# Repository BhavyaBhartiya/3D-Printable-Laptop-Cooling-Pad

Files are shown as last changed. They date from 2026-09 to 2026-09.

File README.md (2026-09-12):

# 3D Printable Laptop Cooling Pad

This is an open source laptop cooling pad designed to force air into the laptop like the Ilano V10 Cooling Pad. It uses 2 Arctic P12 Pro fans set in back portion of the cooling pad instead of th emiddle as most laptops have ducts at the back and not in the middle. It also uses a custom RP2040 based board to control the fan speed on the basis of the temperature of the CPU if in automatic mode or to set the fans to a constant speed if in manual mode. It requires a seperate 12v Power Input to run it without increasing load on the laptop by using the laptop to supply power to it. If it is to be  used in automatic mode then it should be connected to the laptop by a seperate cable so that the laptop can provide it with the CPU temperatures.

## Instructons for Using and Assembly

1. Attach the PCB to the area enclosed by 3 thin walls in between the fan. The PCB should slip in and sit snugly in the enclosure as it has been built to the exact dimensions for the pcb.

2. If you plan on using only manual mode then connect the 6 pin usb c receptacle to an external 12V Power Supply. The 6 pin USB C receptacle is the one on the right of the RP2040 chip.

3. If you wish to use automatic mode as well then attach a cable from any port of the computer to the 14 pin usb c receptacle present straight ahead of the RP2040 chip.

4. The OLED scrren will show current mode, fan speed and if any fan is facing any errors. If it is in automatic mode then it will also show the CPU temperature which will be updated once every 5 seconds.

5. You can use the Increase/ Decrease Buttons to increase or decrease the RPM of the fan by 500 in Manual Mode.

6. You can use the Mode Button to toggle the Mode of the Cooling Pad.

## Schematic

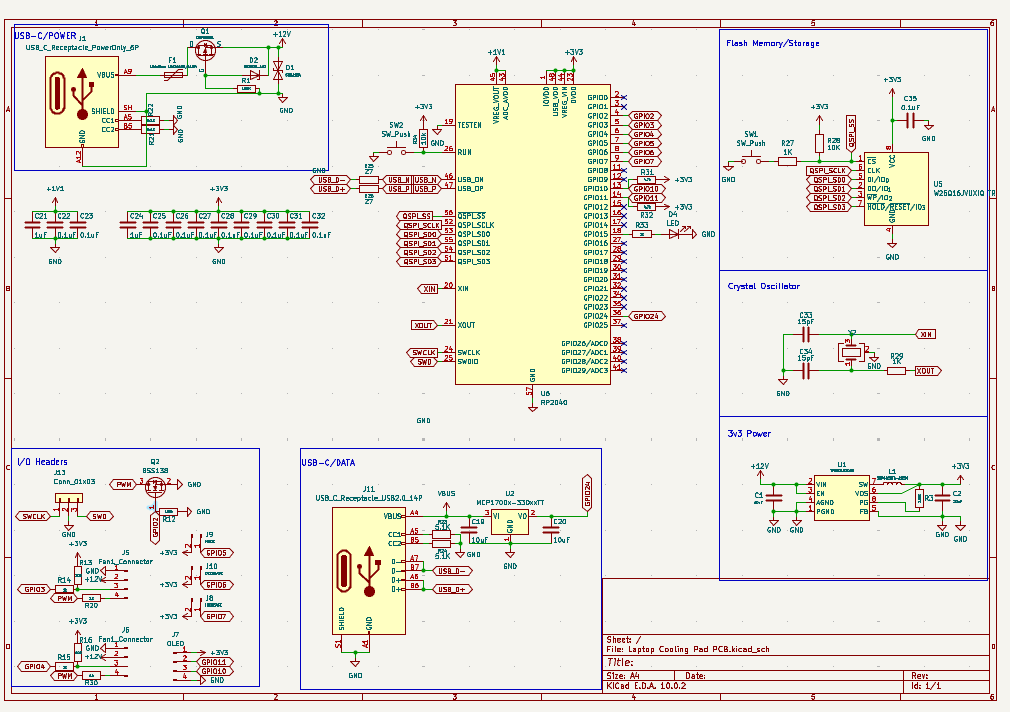
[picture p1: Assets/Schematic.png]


## PCB

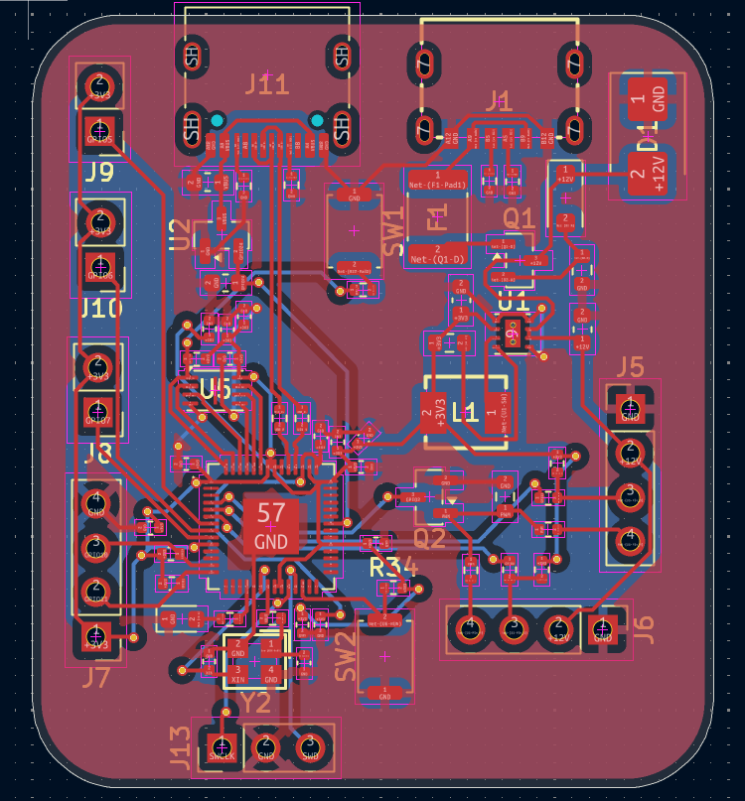
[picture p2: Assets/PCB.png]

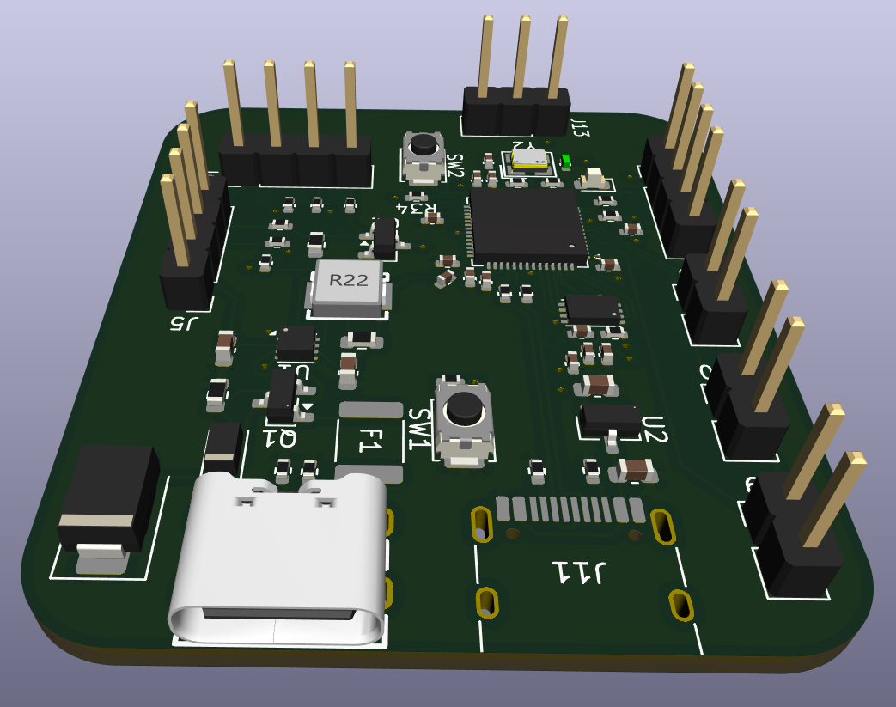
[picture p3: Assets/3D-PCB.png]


## 3D-Design

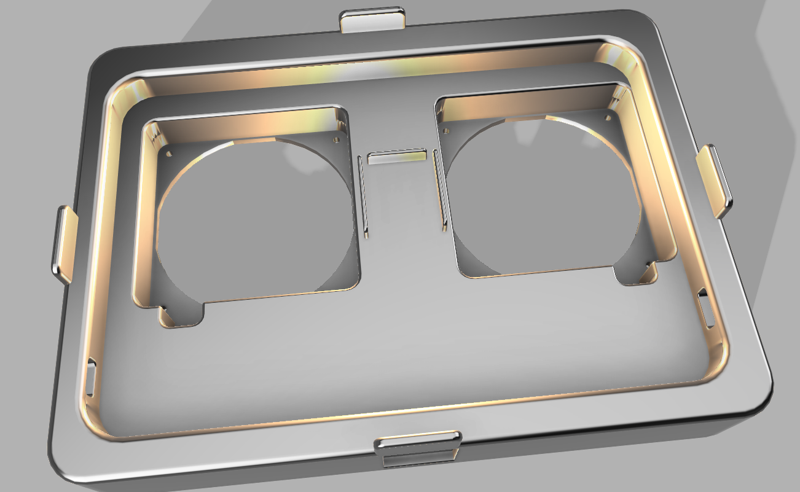
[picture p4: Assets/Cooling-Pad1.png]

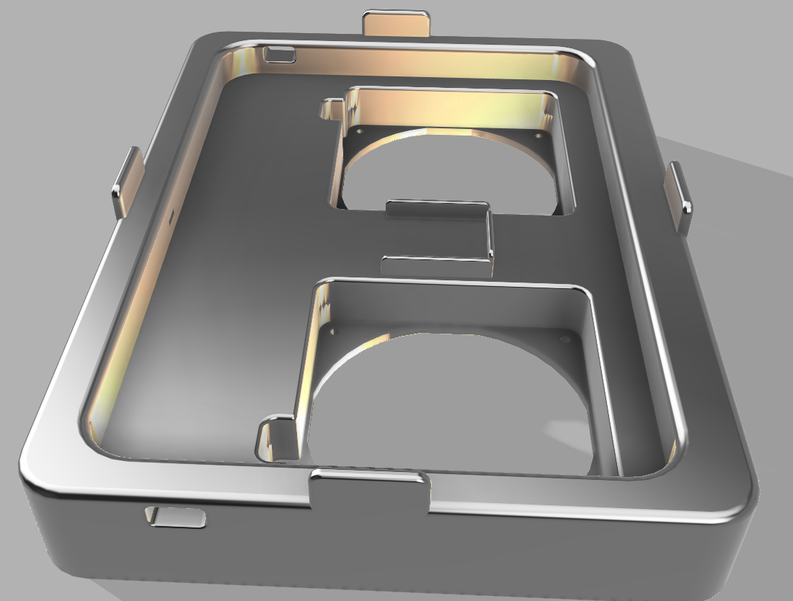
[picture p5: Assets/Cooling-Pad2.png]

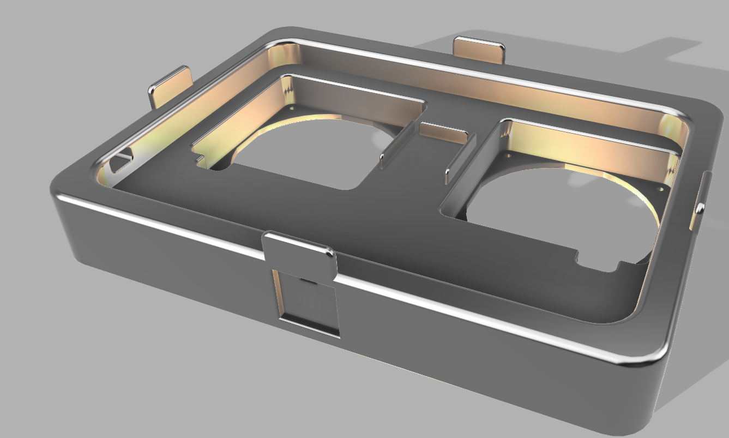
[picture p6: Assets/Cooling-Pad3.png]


## External Circuit

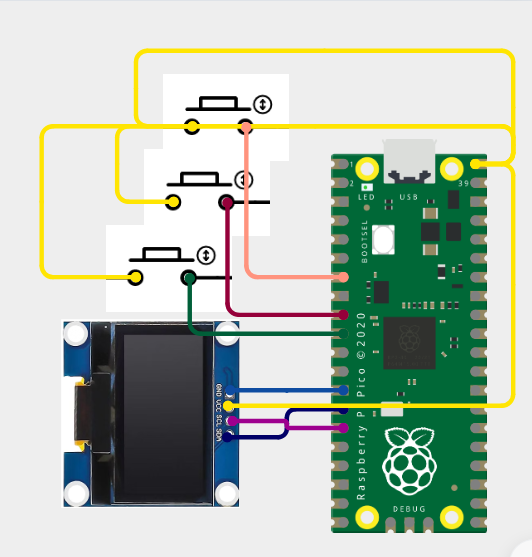
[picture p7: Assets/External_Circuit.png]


## BOM
| Designator | Footprint | Quantity | Value | LCSC Part # | Unit Price USD | Design Qty Cost USD | Link |
|---|---|---|---|---|---|---|---|
| C1, C19, C20 | 603 | 3 | 10uF | C96446 | 0.0557 | 0.1671 | https://www.lcsc.com/product-detail/C96446.html |
| C2 | 603 | 1 | 22uF | C2762594 | 0.1021 | 0.1021 | https://www.lcsc.com/product-detail/C2762594.html |
| C21, C24 | 402 | 2 | 1uF | C52923 | 0.0122 | 0.0244 | https://www.lcsc.com/product-detail/C52923.html |
| C22, C23, C25, C26, C27, C28, C29, C30, C31, C32, C35 | 402 | 11 | 0.1uF | C1525 | 0.0046 | 0.0506 | https://www.lcsc.com/product-detail/C1525.html |
| C33, C34 | 402 | 2 | 15pF | C86285 | 0.004 | 0.008 | https://www.lcsc.com/product-detail/C86285.html |
| D1 | D_SMB | 1 | SMBJ15A | C83846 | 0.1183 | 0.1183 | https://www.lcsc.com/product-detail/C83846.html |
| D2 | D_SOD-123F | 1 | BZT52H-A12 | C7507853 | 0.1912 | 0.1912 | https://www.lcsc.com/product-detail/C7507853.html |
| D4 | 603 | 1 | LED | C965804 | 0.0051 | 0.0051 | https://www.lcsc.com/product-detail/C965804.html |
| F1 | 1812 | 1 | Littelfuse 1812L150/24MR | C142805 | 0.0979 | 0.0979 | https://www.lcsc.com/product-detail/C142805.html |
| J1 | TYPE-C-SMD_TYPE-C-6P-073 | 1 | USB_C_Receptacle_PowerOnly_6P | C668623 | 0.0406 | 0.0406 | https://www.lcsc.com/product-detail/C668623.html |
| J10 | PinHeader_1x02_P2.54mm_Vertical | 1 | DECREASE | C32713268 | 0.0154 | 0.0154 | https://www.lcsc.com/product-detail/C32713268.html |
| J11 | USB_C_Receptacle_HRO_TYPE-C-31-M-12 | 1 | USB_C_Receptacle_USB2.0_14P | C165948 | 0.1724 | 0.1724 | https://www.lcsc.com/product-detail/C165948.html |
| J13 | PinHeader_1x03_P2.54mm_Vertical | 1 | Conn_01x03 | C2937625 | 0.0198 | 0.0198 | https://www.lcsc.com/product-detail/C2937625.html |
| J5, J6 | PinHeader_1x04_P2.54mm_Vertical | 2 | Fan1_Connector | C2691448 | 0.0275 | 0.055 | https://www.lcsc.com/product-detail/C2691448.html |
| J7 | PinHeader_1x04_P2.54mm_Vertical | 1 | OLED | C2691448 | 0.0275 | 0.0275 | https://www.lcsc.com/product-detail/C2691448.html |
| J8 | PinHeader_1x02_P2.54mm_Vertical | 1 | INCREASE | C32713268 | 0.0154 | 0.0154 | https://www.lcsc.com/product-detail/C32713268.html |
| J9 | PinHeader_1x02_P2.54mm_Vertical | 1 | MODE | C32713268 | 0.0154 | 0.0154 | https://www.lcsc.com/product-detail/C32713268.html |
| L1 | IND-SMD_L4.5-W4.1_SRP4020TA | 1 | SRP4020TA-2R2M | C719179 | 0.6015 | 0.6015 | https://www.lcsc.com/product-detail/C719179.html |
| Q1 | SOT-23 | 1 | DMP3099L | C2940610 | 0.0499 | 0.0499 | https://www.lcsc.com/product-detail/C2940610.html |
| Q2 | SOT-23 | 1 | BSS138 | C52895 | 0.0638 | 0.0638 | https://www.lcsc.com/product-detail/C52895.html |
| R1, R12, R3 | 603 | 3 | 100K | C14675 | 0.0036 | 0.0108 | https://www.lcsc.com/product-detail/C14675.html |
| R13, R16, R28, R34 | 402 | 4 | 10K | C60490 | 0.0033 | 0.0132 | https://www.lcsc.com/product-detail/C60490.html |
| R14, R15, R20, R27, R29, R30, R33 | 402 | 7 | 1k | C106235 | 0.0044 | 0.0308 | https://www.lcsc.com/product-detail/C106235.html |
| R21, R22, R23, R24 | 402 | 4 | 5.1K | C105872 | 0.003 | 0.012 | https://www.lcsc.com/product-detail/C105872.html |
| R25, R26 | 402 | 2 | 27 | C138021 | 0.004 | 0.008 | https://www.lcsc.com/product-detail/C138021.html |
| R31, R32 | 402 | 2 | 4.7k | C105871 | 0.0038 | 0.0076 | https://www.lcsc.com/product-detail/C105871.html |
| SW1, SW2 | SW_Push_SPST_NO_Alps_SKRK | 2 | SW_Push | C720477 | 0.053 | 0.106 | https://www.lcsc.com/product-detail/C720477.html |
| U1 | WSON-8-1EP_2x2mm_P0.5mm_EP0.9x1.6mm_ThermalVias | 1 | TPS62162DSG | C2863597 | 1.5159 | 1.5159 | https://www.lcsc.com/product-detail/C2863597.html |
| U2 | SOT-23 | 1 | MCP1700x-330xxTT | C39051 | 0.409 | 0.409 | https://www.lcsc.com/product-detail/C39051.html |
| U5 | Winbond_USON-8-1EP_3x2mm_P0.5mm_EP0.2x1.6mm | 1 | W25Q16JVUXIQ TR | C2843335 | 1.5882 | 1.5882 | https://www.lcsc.com/product-detail/C2843335.html |
| U6 | QFN-56-1EP_7x7mm_P0.4mm_EP3.2x3.2mm | 1 | RP2040 | C2040 | 0.9968 | 0.9968 | https://www.lcsc.com/product-detail/C2040.html |
| Y2 | CRYSTAL-SMD_4P-L2.5-W2.0-BL-1 | 1 | ABM8-272-T3 | C20625731 | 0.62 | 0.62 | https://lcsc.com/product-detail/Crystals_Abracon-LLC-ABM8-272-T3_C20625731.html |
| Arctic P12 Pro | | 2 | | | 16.23 | 32.46 | https://www.arctic.de/en/P12-Pro/ACFAN00305A |
| TOTAL | | 66 | | | | 39.6197 | |

### Credits - to KaiPereira for their excellent guide on [how to buid a custom devboard](https://github.com/KaiPereira/build-a-devboard)

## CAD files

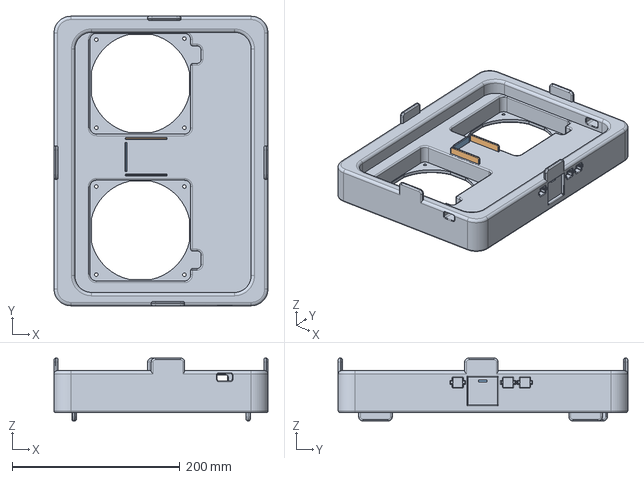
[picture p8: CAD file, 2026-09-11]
src/3D-Print/Laptop Cooling Pad.step
255.0 x 345.0 x 75.0 mm

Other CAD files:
src/3D-Print/Laptop Cooling Pad.f3d

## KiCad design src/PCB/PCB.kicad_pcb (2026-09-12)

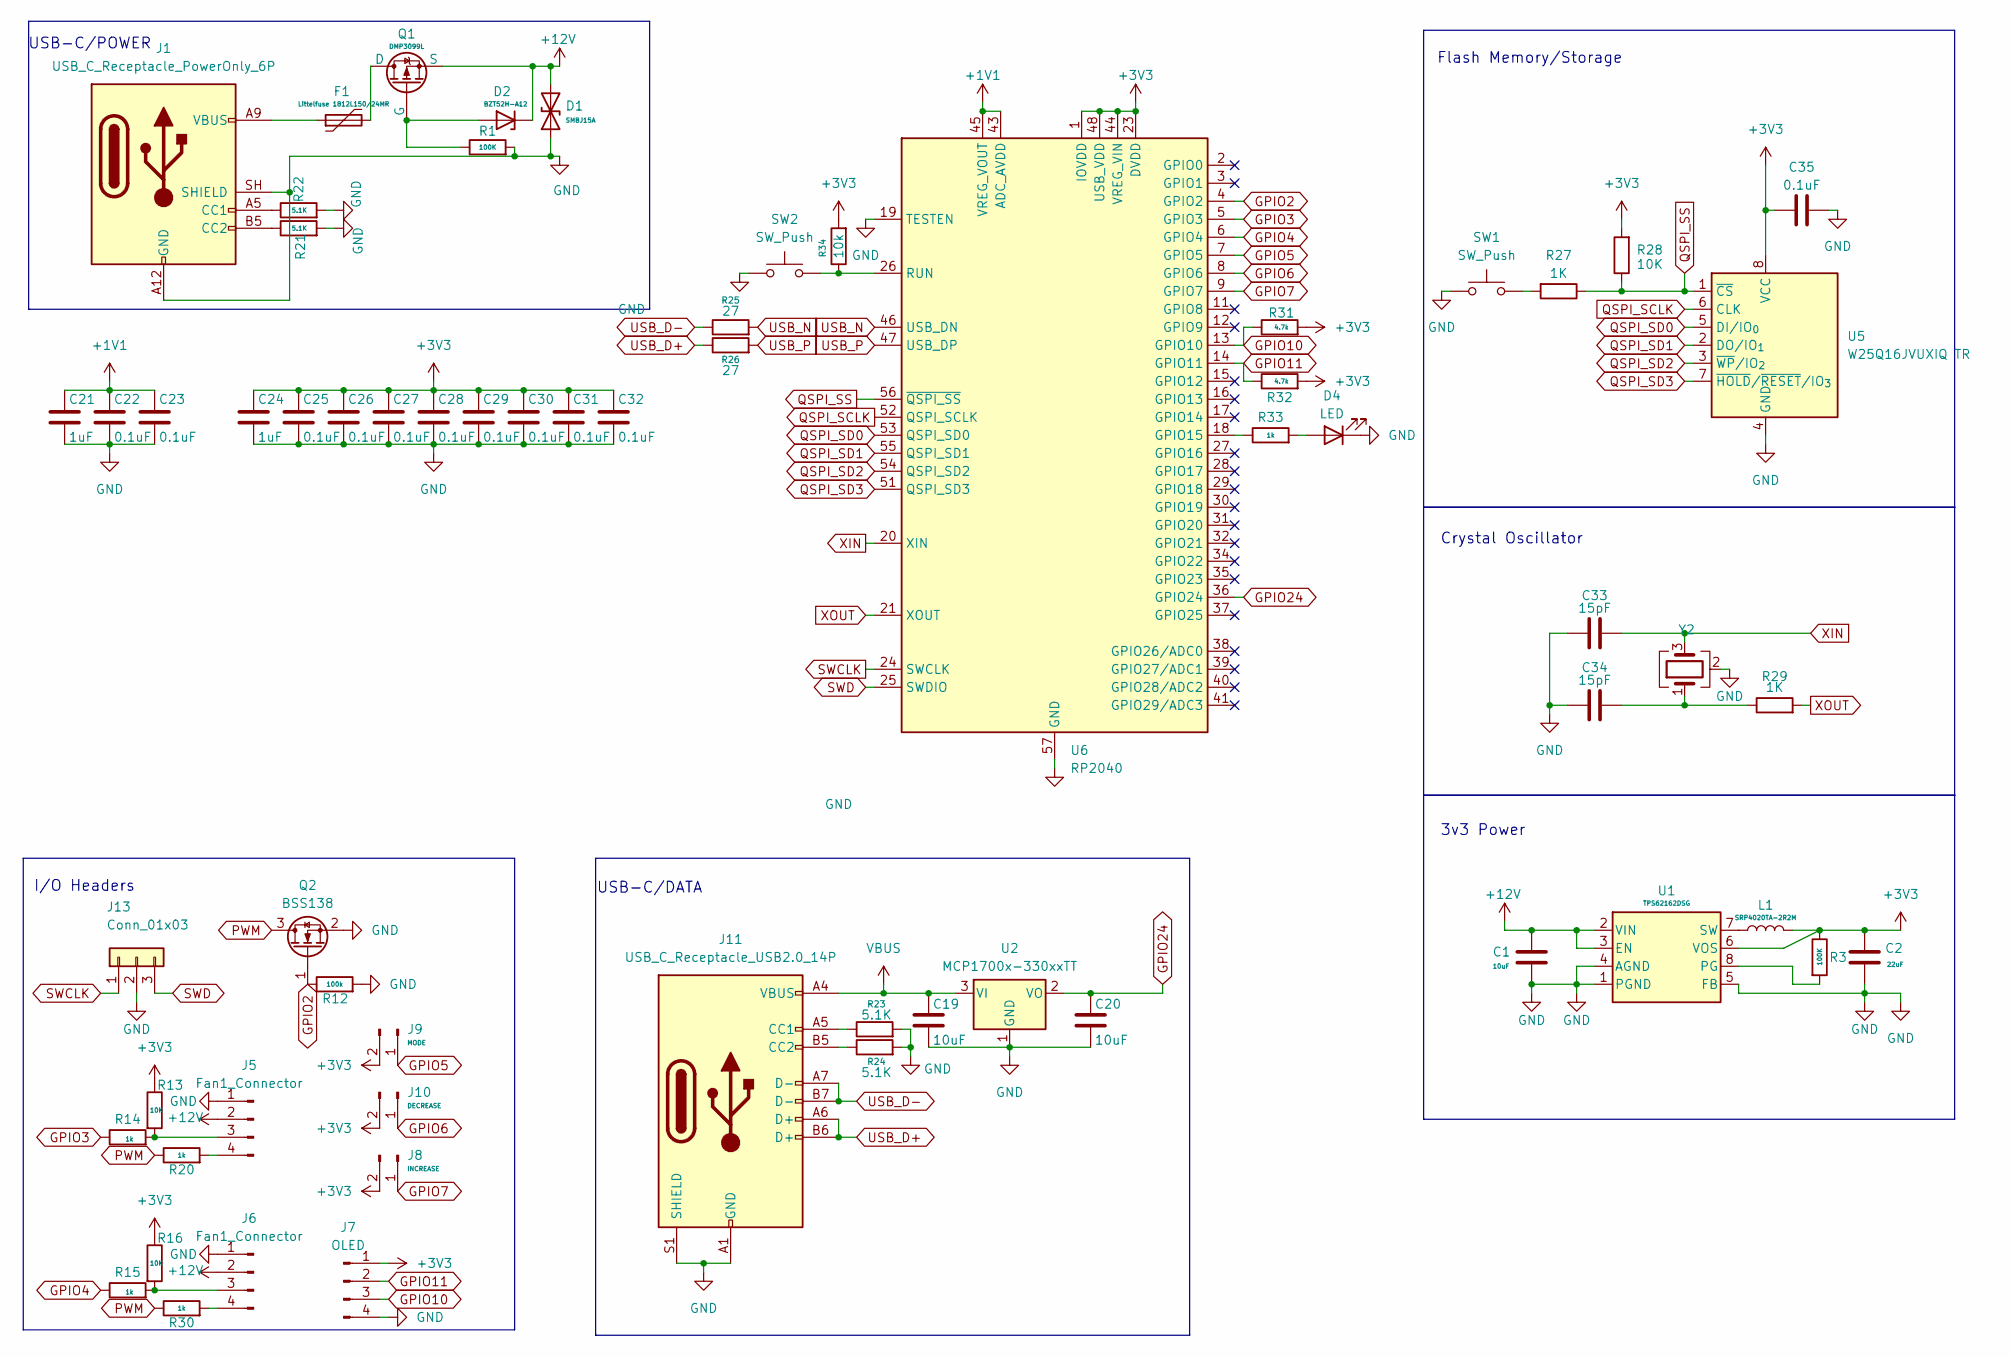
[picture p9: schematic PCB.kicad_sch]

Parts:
C1, C19, C20: 10uF; C_0603_1608Metric; LCSC Part Number C96446
C2: 22uF; C_0603_1608Metric; LCSC Part Number C2762594
C21, C24: 1uF; C_0402_1005Metric; LCSC Part Number C52923
C22, C23, C25, C26, C27, C28, C29, C30, C31, C32, C35: 0.1uF; C_0402_1005Metric; LCSC Part Number C1525
C33, C34: 15pF; C_0402_1005Metric; LCSC Part Number C86285
D1: SMBJ15A; D_SMB; LCSC Part Number C83846
D2: BZT52H-A12; D_SOD-123F; LCSC Part Number C7507853
D4: LED; LED_0603_1608Metric; LCSC Part Number C965804
F1: Littelfuse 1812L150/24MR; Fuse_1812_4532Metric; LCSC Part Number C142805
J1: USB_C_Receptacle_PowerOnly_6P; TYPE-C-SMD_TYPE-C-6P-073; LCSC Part Number TYPE-C 6P(073)
J5, J6: Fan1_Connector; PinHeader_1x04_P2.54mm_Vertical; LCSC Part Number C2691448
J7: OLED; PinHeader_1x04_P2.54mm_Vertical; LCSC Part Number C2691448
J8: INCREASE; PinHeader_1x02_P2.54mm_Vertical; LCSC Part Number C32713268
J9: MODE; PinHeader_1x02_P2.54mm_Vertical; LCSC Part Number C32713268
J10: DECREASE; PinHeader_1x02_P2.54mm_Vertical; LCSC Part Number C32713268
J11: USB_C_Receptacle_USB2.0_14P; USB_C_Receptacle_HRO_TYPE-C-31-M-12; LCSC Part Number C165948
J13: Conn_01x03; PinHeader_1x03_P2.54mm_Vertical; LCSC Part Number C2937625
L1: SRP4020TA-2R2M; IND-SMD_L4.5-W4.1_SRP4020TA; LCSC Part Number C719179
Q1: DMP3099L; SOT-23; LCSC Part Number C2940610
Q2: BSS138; SOT-23; LCSC Part Number C52895
R1, R3: 100K; R_0603_1608Metric; LCSC Part Number C14675
R12: 100k; R_0603_1608Metric; LCSC Part Number C14675
R13, R16, R28: 10K; R_0402_1005Metric; LCSC Part Number C60490
R14, R15, R20, R30, R33: 1k; R_0402_1005Metric; LCSC Part Number C106235
R21, R22, R23, R24: 5.1K; R_0402_1005Metric; LCSC Part Number C105872
R25, R26: 27; R_0402_1005Metric; LCSC Part Number C138021
R27, R29: 1K; R_0402_1005Metric; LCSC Part Number C106235
R31, R32: 4.7k; R_0402_1005Metric; LCSC Part Number C105871
R34: 10k; R_0402_1005Metric; LCSC Part Number C60490
SW1, SW2: SW_Push; SW_Push_SPST_NO_Alps_SKRK; LCSC Part Number C720477
U1: TPS62162DSG; WSON-8-1EP_2x2mm_P0.5mm_EP0.9x1.6mm_ThermalVias; LCSC Part Number C2863597
U2: MCP1700x-330xxTT; SOT-23; LCSC Part Number C39051
U5: W25Q16JVUXIQ TR; Winbond_USON-8-1EP_3x2mm_P0.5mm_EP0.2x1.6mm; LCSC Part Number C2843335
U6: RP2040; QFN-56-1EP_7x7mm_P0.4mm_EP3.2x3.2mm; LCSC Part Number C2040
Y2: ABM8-272-T3; CRYSTAL-SMD_4P-L2.5-W2.0-BL-1; LCSC Part Number C20625731

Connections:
+1V1: C21.1, C22.1, C23.1, U6.43 (ADC_AVDD), U6.45 (VREG_VOUT)
+3V3: C2.1, C24.1, C25.1, C26.1, C27.1, C28.1, C29.1, C30.1, C31.1, C32.1, C35.1, J7.1, J8.2, J9.2, J10.2, L1.2, R3.1, R13.1, R16.1, R28.2, R31.2, R32.2, R34.2, U1.6 (VOS), U5.8 (VCC), U6.1 (IOVDD), U6.10 (IOVDD), U6.22 (IOVDD), U6.23 (DVDD), U6.33 (IOVDD), U6.42 (IOVDD), U6.44 (VREG_VIN), U6.48 (USB_VDD), U6.49 (IOVDD), U6.50 (DVDD)
+12V: C1.1, D1.2 (A2), D2.1 (K), J5.2, J6.2, Q1.3 (S), U1.2 (VIN), U1.3 (EN)
GND: C1.2, C2.2, C19.2, C20.2, C21.2, C22.2, C23.2, C24.2, C25.2, C26.2, C27.2, C28.2, C29.2, C30.2, C31.2, C32.2, C33.1, C34.1, C35.2, D1.1 (A1), D4.1 (K), J1.A12 (GND), J1.B12 (GND), J1.SH (SHIELD), J5.1, J6.1, J7.4, J11.A1 (GND), J11.A12 (GND), J11.B1 (GND), J11.B12 (GND), J11.S1 (SHIELD), J13.2, Q2.2 (S), R1.2, R12.2, R21.2, R22.2, R23.2, R24.2, SW1.1, SW2.1, U1.1 (PGND), U1.4 (AGND), U1.5 (FB), U2.1 (GND), U5.4 (GND), U6.19 (TESTEN), U6.57 (GND), Y2.2 (G), Y2.4 (G)
GPIO2: Q2.1 (G), R12.1, U6.4 (GPIO2)
GPIO3: R14.1, U6.5 (GPIO3)
GPIO4: R15.1, U6.6 (GPIO4)
GPIO5: J9.1, U6.7 (GPIO5)
GPIO6: J10.1, U6.8 (GPIO6)
GPIO7: J8.1, U6.9 (GPIO7)
GPIO10: J7.3, R31.1, U6.13 (GPIO10)
GPIO11: J7.2, R32.1, U6.14 (GPIO11)
GPIO24: C20.1, U2.2 (VO), U6.36 (GPIO24)
unnamed: C34.2, R29.1, Y2.1
unnamed: D2.2 (A), Q1.2 (G), R1.1
unnamed: D4.2 (A), R33.2
unnamed: F1.1, J1.A9 (VBUS), J1.B9 (VBUS)
unnamed: J1.A5 (CC1), R21.1
unnamed: J1.B5 (CC2), R22.1
unnamed: J5.3, R13.2, R14.2
unnamed: J5.4, R20.2
unnamed: J6.3, R15.2, R16.2
unnamed: J6.4, R30.2
unnamed: J11.A5 (CC1), R23.1
unnamed: J11.B5 (CC2), R24.1
unnamed: F1.2, Q1.1 (D)
unnamed: R27.2, SW1.2
unnamed: R3.2, U1.8 (PG)
unnamed: L1.1, U1.7 (SW)
unnamed: R33.1, U6.18 (GPIO15)
unnamed: R34.1, SW2.2, U6.26 (RUN)
PWM: Q2.3 (D), R20.1, R30.1
QSPI_SCLK: U5.6 (CLK), U6.52 (QSPI_SCLK)
QSPI_SD0: U5.5 (DI/IO_{0}), U6.53 (QSPI_SD0)
QSPI_SD1: U5.2 (DO/IO_{1}), U6.55 (QSPI_SD1)
QSPI_SD2: U5.3 (~WP/IO_{2}), U6.54 (QSPI_SD2)
QSPI_SD3: U5.7 (~HOLD/~RESET/IO_{3}), U6.51 (QSPI_SD3)
QSPI_SS: R27.1, R28.1, U5.1 (~CS), U6.56 (~QSPI_SS)
SWCLK: J13.1, U6.24 (SWCLK)
SWD: J13.3, U6.25 (SWDIO)
USB_D+: J11.A6 (D+), J11.B6 (D+), R26.1
USB_D-: J11.A7 (D-), J11.B7 (D-), R25.1
USB_N: R25.2, U6.46 (USB_DN)
USB_P: R26.2, U6.47 (USB_DP)
VBUS: C19.1, J11.A4 (VBUS), J11.A9 (VBUS), J11.B4 (VBUS), J11.B9 (VBUS), U2.3 (VI)
XIN: C33.2, U6.20 (XIN), Y2.3
XOUT: R29.2, U6.21 (XOUT)

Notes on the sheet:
I/O Headers
USB-C/DATA
Crystal Oscillator
Flash Memory/Storage
USB-C/POWER
3v3 Power

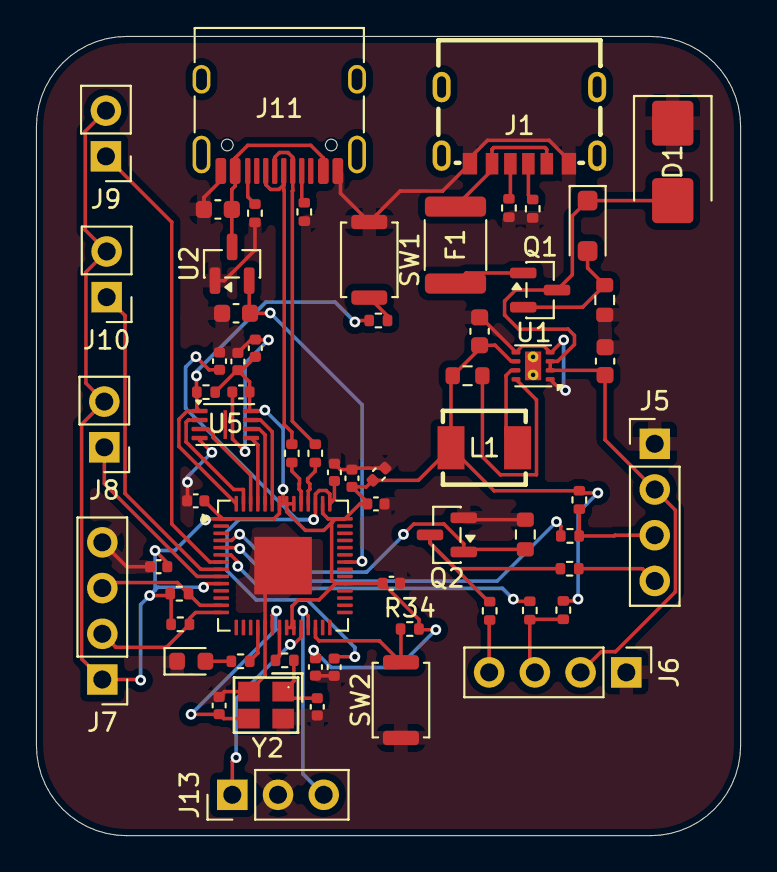
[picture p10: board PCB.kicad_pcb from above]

Board: 2 copper layers, 39.1 x 44.4 mm, 64 parts (0 on the bottom side), 47 nets.

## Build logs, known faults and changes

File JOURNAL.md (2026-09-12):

---
title: "3D-Printable-Laptop-Cooling-Pas"
author: "Enigma_124"
description: "This is a 3D printable Laptop Cooling Pad using Fan controlled by a custom RP2040 based devboard"
created_at: "2026-09-12"
---

So I had no idea that I had to both write devlogs and lapse. I thought it was one or the other, so here is a condensed form of the devlogs. 

# 2026-08-18 to 2026-08-19
 I was building the voltage protection circuit, which would allow the fans to receive a stable current at 12v and prevent reverse polarity. Then I created a step down convertor cicuit for 12v to 3.3.

 **Total time spent: 1.5 hours**

# 2026-08-20 to 2026-08-21
 I focused on creating the circuit for the RP2040 microcontroller and connected the required pins to the 4-pin headers for the fans and the OLED screen. I also connected the 3 2-pin headers for connecting various buttons. A separate USB-C port was added, which would receive CPU temperatures from the laptop.

 **Total time spent: 2 hours**

# 2026-08-23 to 2026-08-26
 I worked on assigning the various footprints and placing components in the PCB editor. Here KaiPereira's guide was very useful in deciding footprints of various components.

 **Total time spent: 4 hours**

# 2026-08-26 to 2026-08-27
 I worked on the traces. At first, I made the board a 4-layer board as I thought the routing would require the extra space, but I was able to route it in 2 layers. While routing the differential pair on the USB-C port for supplying data, it felt as if it didn't want to route to the RP2040.

 **Total time spent: 1.5 hours**

# 2026-09-03 to 2026-09-10
 I worked on the 3D Structure of the laptop Cooling Pad. This was my second time using Fusion, so the work was slow. Nothing much to say here. Also Worked on Readme.

 **Total time spent: 6 hours**

# 2026-09-11 to 2026-09-12
 I worked on the code for the RP2040. The imports in the code kept throwing errors even after reinstalling CMake and all the C compilers. The errors were fixed when I opened the folder separately and reran the build instead of opening the parent folder in VS Code. Also completed the Journal.md.

 **Total time spent: 2 hours**

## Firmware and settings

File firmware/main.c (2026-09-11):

#include "pico/stdlib.h"
#include "hardware/pwm.h"
#include "hardware/gpio.h"
#include "ssd1306.h"
#include <stdio.h>
#include <stdlib.h>
#include <string.h>

#define PWM_PIN  2
#define TACH1    3
#define TACH2    4
#define MODE     5
#define DOWN     6
#define UP       7

#define MIN_RPM  500
#define MAX_RPM  3300
#define STEP_RPM 500
#define PPR      2

volatile uint32_t tach1 = 0, tach2 = 0;

uint16_t rpm1 = 0, rpm2 = 0;
uint16_t target = 1500;
uint16_t manual_target = 1500;

uint8_t duty = 60;

bool auto_mode = false;
bool stopped = false;
bool temp_valid = false;

float cpu_temp = 0;
uint32_t temp_time = 0;

void tach_irq(uint gpio, uint32_t events) {
    if (gpio == TACH1) tach1++;
    else if (gpio == TACH2) tach2++;
}

void set_fan(uint8_t d) {
    if (d > 100) d = 100;
    pwm_set_gpio_level(PWM_PIN, (100 - d) * 10);
}

uint16_t temp_rpm(float t) {
    if (t < 40) return 700;
    if (t < 50) return 1000;
    if (t < 60) return 1500;
    if (t < 70) return 2000;
    if (t < 80) return 2500;
    return 3000;
}

void buttons(void) {
    static bool last_m = 0, last_u = 0, last_d = 0;
    bool m = gpio_get(MODE);
    bool u = gpio_get(UP);
    bool d = gpio_get(DOWN);

    if (m && !last_m) {
        auto_mode = !auto_mode;
        if (!auto_mode)
            target = manual_target;
    }

    if (!auto_mode) {
        if (u && !last_u) {
            if (manual_target < MAX_RPM)
                manual_target += STEP_RPM;
            target = manual_target;
        }
        if (d && !last_d) {
            if (manual_target > MIN_RPM)
                manual_target -= STEP_RPM;
            target = manual_target;
        }
    }

    last_m = m;
    last_u = u;
    last_d = d;

    sleep_ms(30);
}

void serial(void) {
    static char buf[32];
    static uint8_t n = 0;
    int c;

    while ((c = getchar_timeout_us(0)) != PICO_ERROR_TIMEOUT) {
        if (c == '\n' || c == '\r') {
            buf[n] = 0;
            if (!strncmp(buf, "TEMP ", 5)) {
                cpu_temp = strtof(buf + 5, NULL);
                temp_valid = true;
                temp_time = to_ms_since_boot(get_absolute_time());
            }
            else if (!strcmp(buf, "AUTO")) {
                auto_mode = true;
            }
            else if (!strcmp(buf, "MANUAL")) {
                auto_mode = false;
                target = manual_target;
            }
            else if (!strncmp(buf, "RPM ", 4)) {
                int r = atoi(buf + 4);
                if (r < MIN_RPM) r = MIN_RPM;
                if (r > MAX_RPM) r = MAX_RPM;
                manual_target = r;
                target = r;
                auto_mode = false;
            }
            else if (!strcmp(buf, "STOP")) {
                stopped = true;
                set_fan(0);
            }
            else if (!strcmp(buf, "START")) {
                stopped = false;
            }

            n = 0;
        }
        else if (n < sizeof(buf) - 1) {
            buf[n++] = c;
        }
    }
}

void control(void) {
    static uint32_t last = 0;
    uint32_t now = to_ms_since_boot(get_absolute_time());

    if (now - last < 1000)
        return;
    uint32_t elapsed = now - last;
    last = now;
    uint32_t p1 = tach1;
    uint32_t p2 = tach2;
    tach1 = 0;
    tach2 = 0;

    rpm1 = (p1 * 60000) / (PPR * elapsed);
    rpm2 = (p2 * 60000) / (PPR * elapsed);

    if (auto_mode) {
        if (temp_valid && now - temp_time < 10000)
            target = temp_rpm(cpu_temp);
        else
            target = 0;
    }
    if (stopped || target == 0) {
        duty = 0;
        set_fan(0);
        return;
    }
    uint16_t avg = (rpm1 + rpm2) / 2;
    if (avg < target - 80) {
        if (duty < 100) duty += 2;
    }
    else if (avg > target + 80) {
        if (duty > 2) duty -= 2;
    }
    set_fan(duty);
}

void display(void) {
    static uint32_t last = 0;
    uint32_t now = to_ms_since_boot(get_absolute_time());

    if (now - last < 500)
        return;
    last = now;
    char s[24];
    ssd1306_clear();

    sprintf(s, "%s %u", auto_mode ? "AUTO" : "MANUAL", target);
    ssd1306_draw_text(0, 0, s);
    sprintf(s, "F1 %u", rpm1);
    ssd1306_draw_text(0, 16, s);
    sprintf(s, "F2 %u", rpm2);
    ssd1306_draw_text(0, 28, s);

    if (temp_valid && now - temp_time < 10000)
        sprintf(s, "CPU %.1fC", cpu_temp);
    else
        sprintf(s, "CPU --");

    ssd1306_draw_text(0, 40, s);
    sprintf(s, "PWM %u%%", duty);
    ssd1306_draw_text(0, 52, s);
    ssd1306_update();
}

int main(void) {
    stdio_init_all();

    gpio_init(MODE);
    gpio_init(DOWN);
    gpio_init(UP);

    gpio_set_dir(MODE, GPIO_IN);
    gpio_set_dir(DOWN, GPIO_IN);
    gpio_set_dir(UP, GPIO_IN);

    gpio_pull_down(MODE);
    gpio_pull_down(DOWN);
    gpio_pull_down(UP);

    gpio_init(TACH1);
    gpio_init(TACH2);

    gpio_set_dir(TACH1, GPIO_IN);
    gpio_set_dir(TACH2, GPIO_IN);

    gpio_pull_up(TACH1);
    gpio_pull_up(TACH2);

    gpio_set_irq_enabled_with_callback(TACH1, GPIO_IRQ_EDGE_RISE, true, &tach_irq);
    gpio_set_irq_enabled(TACH2, GPIO_IRQ_EDGE_RISE, true);
    gpio_set_function(PWM_PIN, GPIO_FUNC_PWM);

    uint slice = pwm_gpio_to_slice_num(PWM_PIN);

    pwm_config cfg = pwm_get_default_config();
    pwm_config_set_clkdiv(&cfg, 5.0f);
    pwm_config_set_wrap(&cfg, 999);

    pwm_init(slice, &cfg, true);
    set_fan(duty);
    ssd1306_init();

    while (true) {
        serial();
        buttons();
        control();
        display();

        tight_loop_contents();
    }
}

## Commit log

2026-09-11 Creating Repository
    [Laptop Cooling Pad PCB.kicad_pcb, Laptop Cooling Pad PCB.kicad_sch, Laptop Cooling Pad.f3d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]
2026-09-12 adding production files
    [Laptop Cooling Pad.f3d, Laptop Cooling Pad.step, PCB.kicad_pcb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]
2026-09-12 Fixing BOM
    [Complete_bom.csv, PCB.kicad_sch, PCB_BOM.csv]
